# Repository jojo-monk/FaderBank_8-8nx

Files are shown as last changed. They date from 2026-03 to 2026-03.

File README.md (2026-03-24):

# 8+8nx Faderbank

A modular faderbank based on the [16nx](https://github.com/16n-faderbank/16nx) project, designed for Eurorack synthesizers and DAW MIDI control. Sends MIDI data and CV signals.

---
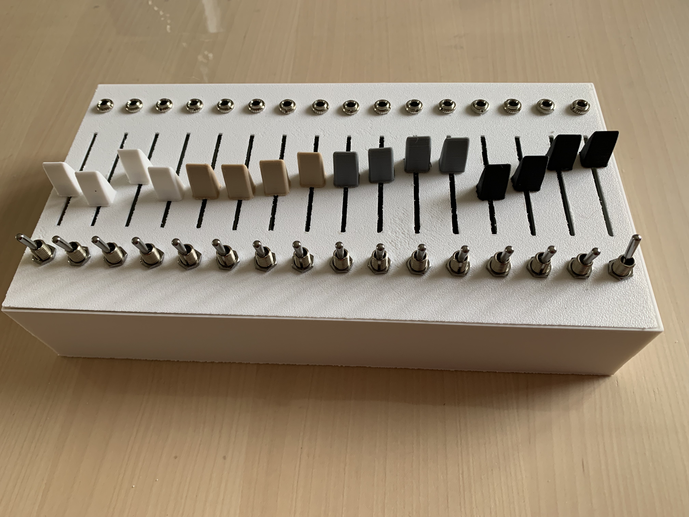
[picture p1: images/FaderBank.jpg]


## What is it?

The 8+8nx is a DIY faderbank that splits the original 16nx design into two separate PCBs, making it more flexible and easier to build in different configurations.

It is designed for musicians who want hands-on control over their Eurorack setup or DAW, with a compact and modular form factor.

---

## Differences from the 16nx

| Feature | 16nx | 8+8nx |
|---|---|---|
| PCB | Single board | 2 PCBs (ControlBoard + MainBoard) |
| Faders | 16 | 8 per ControlBoard (expandable to 16) |
| MCU | RP2040 chip | Raspberry Pi Pico |
| Mute switches | No | Yes, per fader |
| I2C port | Yes | Removed |
| GPIO exposure | Partial | All free Pico pins exposed |

---
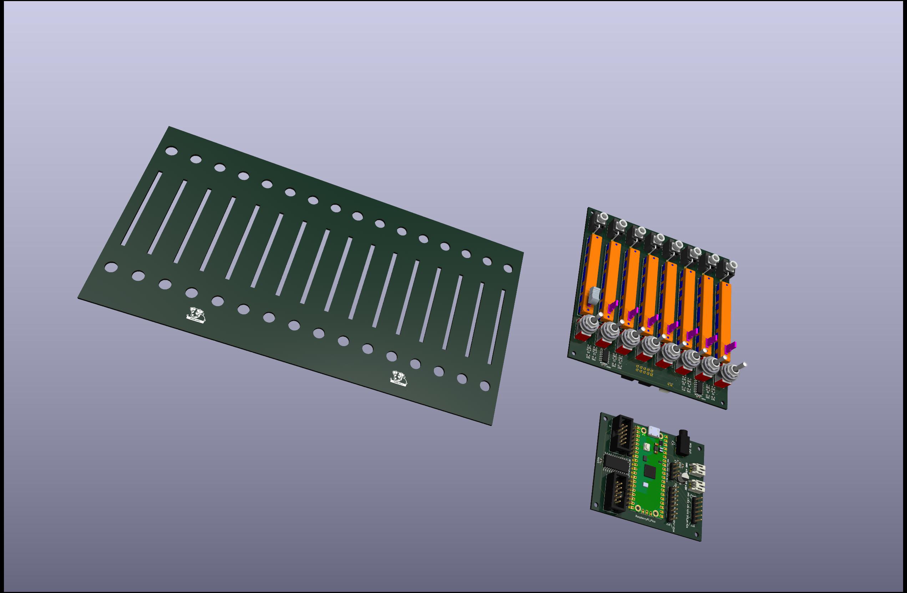
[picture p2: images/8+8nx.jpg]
Rendu 3D


## Hardware

- **MainBoard** — hosts the Raspberry Pi Pico, handles USB MIDI, CV outputs and all connections
- **ControlBoard** — hosts 8 faders and mute switches, connects to the MainBoard

You can run a single ControlBoard (8 faders) or chain two for a full 16-fader setup.

---

## Features

- USB MIDI output
- CV output
- 8 or 16 fader configuration
- Mute switch per fader
- All free GPIO pins of the Raspberry Pi Pico exposed for customization
- Compatible with Eurorack synthesizers and DAWs

---

## Firmware

Based on the 16nx firmware, adapted for the Raspberry Pi Pico.

### Build requirements

- [Raspberry Pi Pico SDK](https://github.com/raspberrypi/pico-sdk)
- CMake 3.13+
- ARM GCC toolchain

### Build

```bash
git clone https://github.com/jojo-monk/8-8nx.git
cd 8-8nx/firmware
mkdir build && cd build
cmake ..
make
```

Flash the resulting `.uf2` file onto your Pico by holding BOOTSEL while plugging it in, then drag and drop the file.

---

## Project status

✅ Tested and working

---

## Credits

Based on the [16nx faderbank](https://github.com/16n-faderbank/16nx) project.

---

## License

Hardware and firmware released under the same license as the original 16nx project.

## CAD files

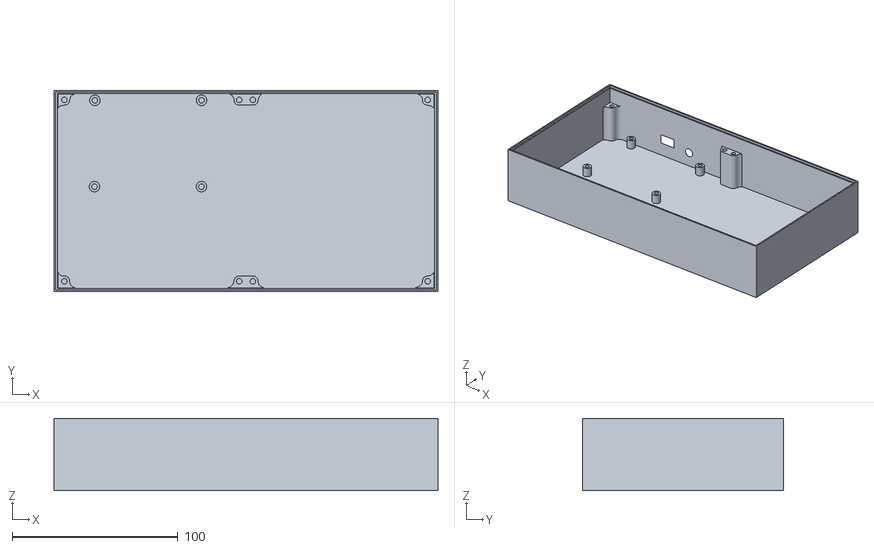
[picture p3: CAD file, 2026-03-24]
3D/88nx-Box.stl
231.9 x 121.6 x 43.5

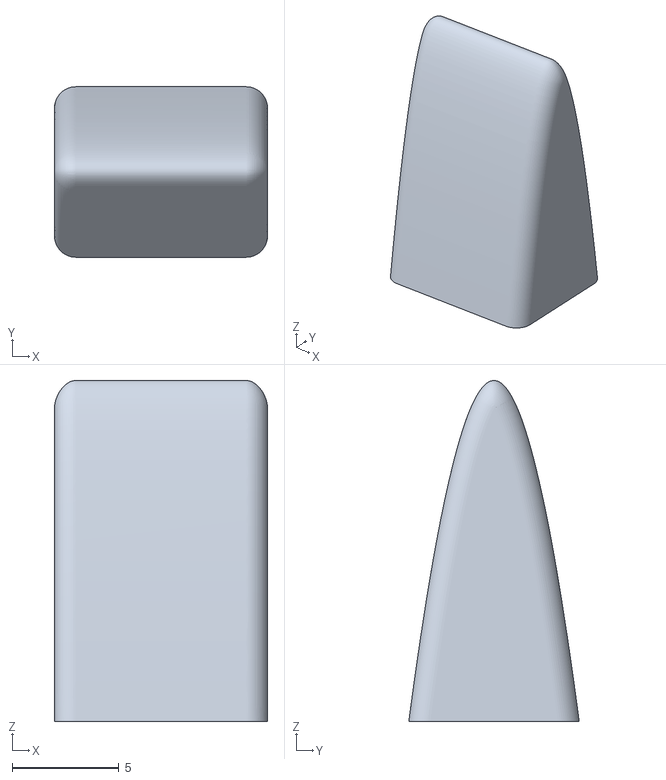
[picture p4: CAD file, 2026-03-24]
3D/fader.stl
10.0 x 8.00 x 16.0

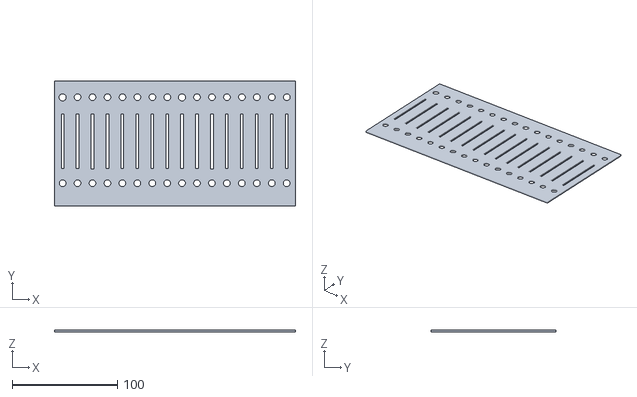
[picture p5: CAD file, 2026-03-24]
3D/8nx-panel.stl
229.0 x 119.0 x 1.51

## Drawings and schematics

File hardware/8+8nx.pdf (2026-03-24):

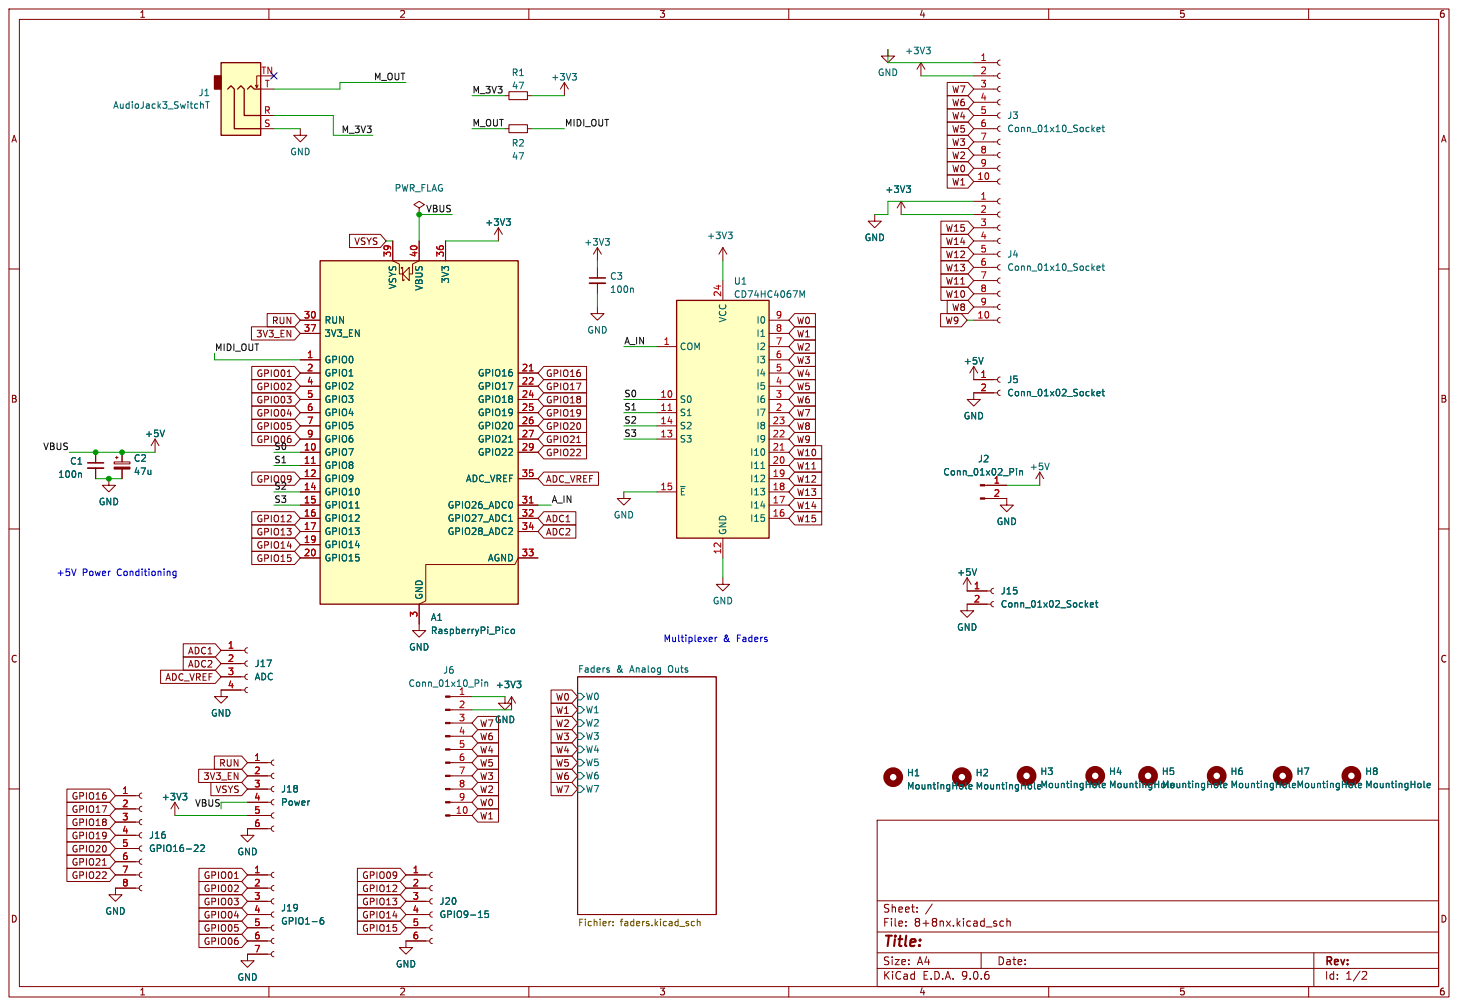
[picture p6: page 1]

Id: 1/2 Title: File: 8+8nx.kicad_sch Sheet: / W0 W7 W6 W3 W2 W4 W5 W1 Faders & Analog Outs Fichier: faders.kicad_sch

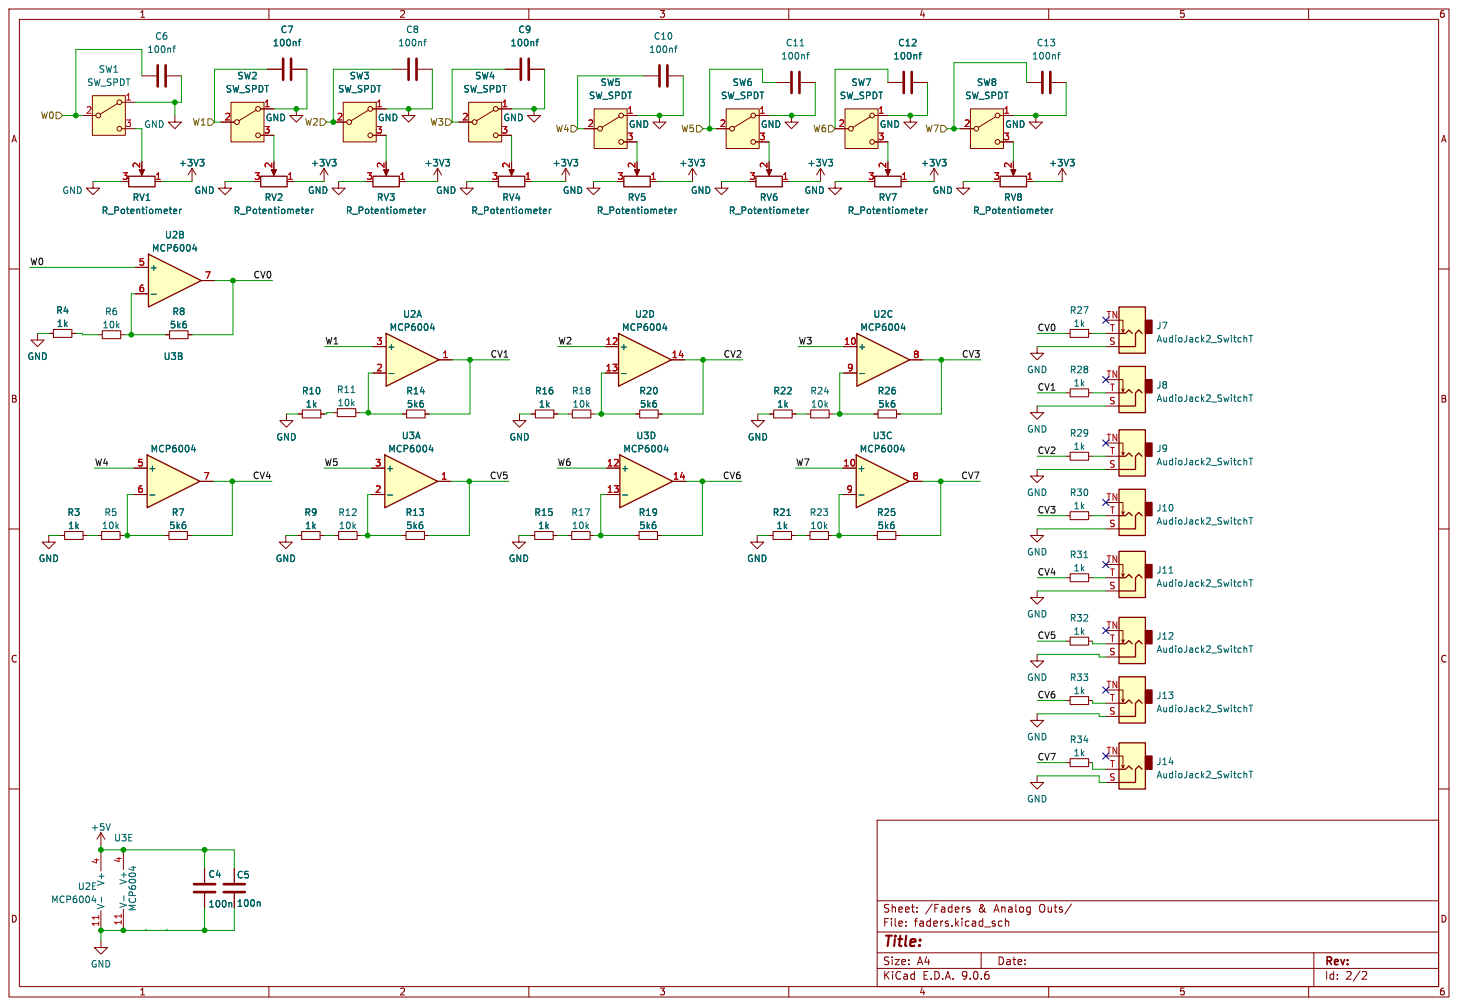
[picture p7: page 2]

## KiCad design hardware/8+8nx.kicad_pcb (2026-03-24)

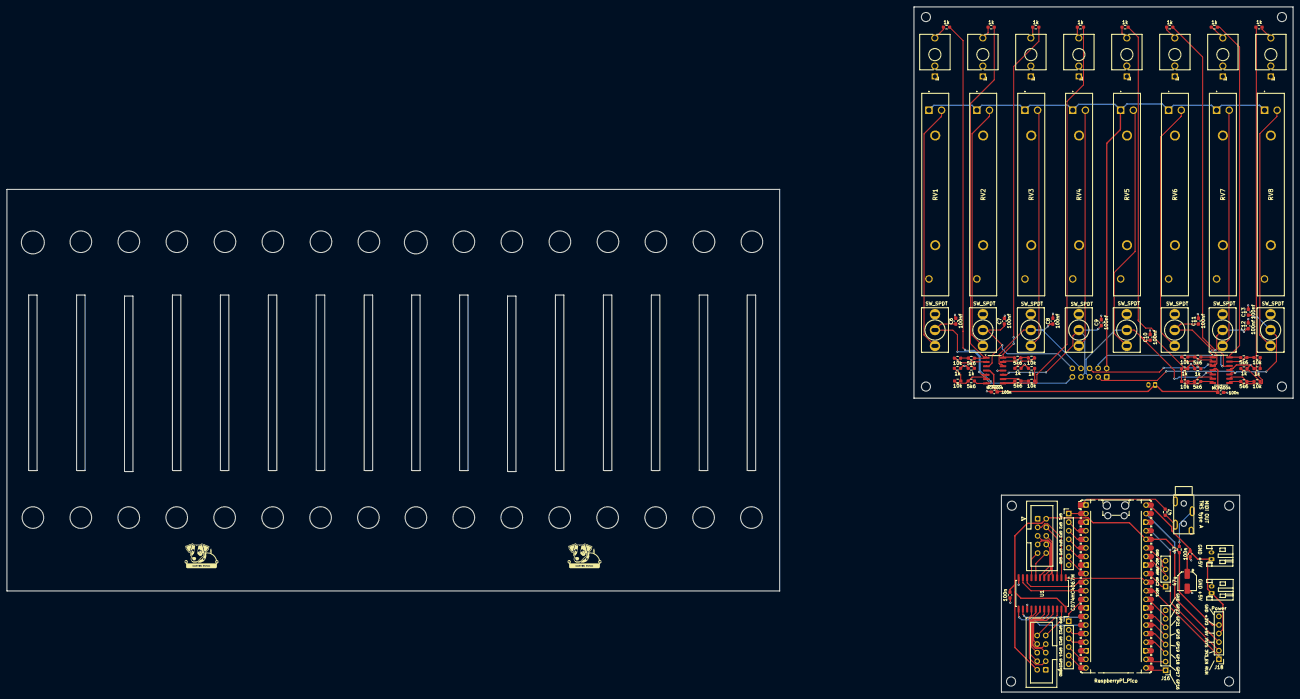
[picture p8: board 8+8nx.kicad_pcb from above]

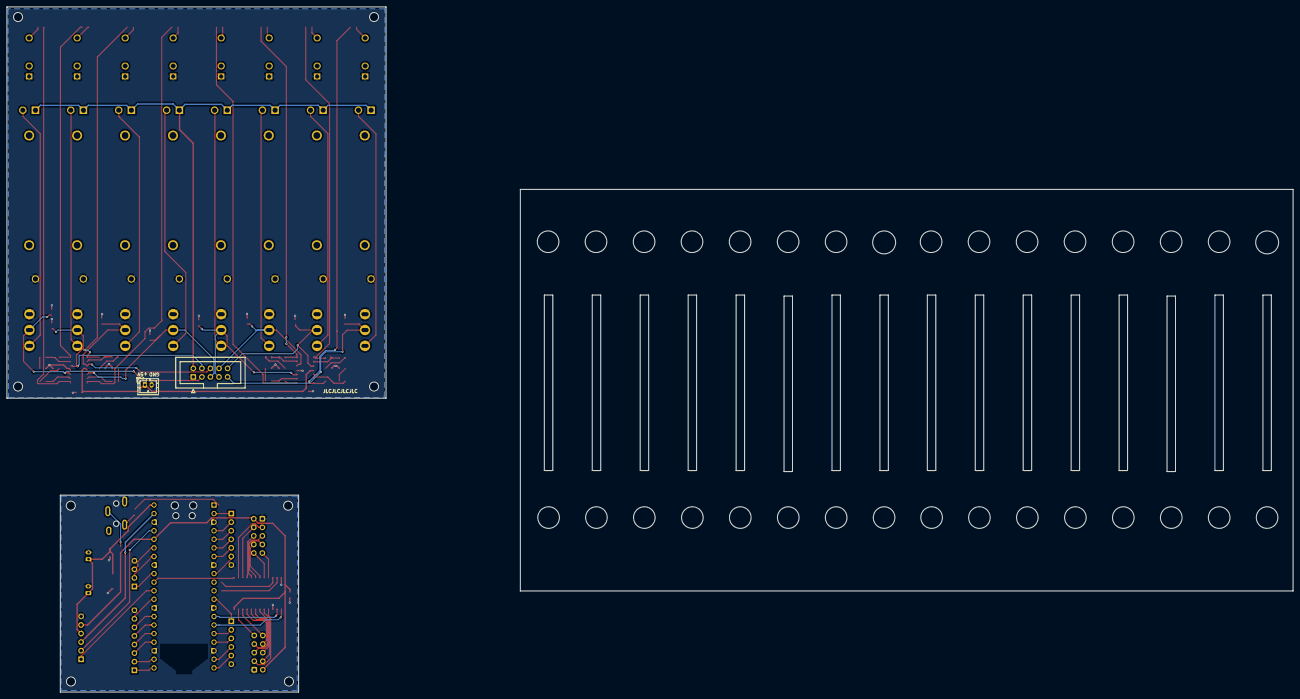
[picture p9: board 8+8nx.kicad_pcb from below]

Board: 2 copper layers, 112.4 x 116.0 mm, 95 parts (2 on the bottom side), 91 nets.

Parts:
A1: RaspberryPi_Pico; RaspberryPi_Pico_Common_Unspecified
C1, C3, C4, C5: 100n; C_0603_1608Metric_Pad1.08x0.95mm_HandSolder
C2: 47u; CP_Elec_5x5.4
C6, C7, C8, C9, C10, C11, C12, C13: 100nf; C_0603_1608Metric_Pad1.08x0.95mm_HandSolder
H1, H2, H3, H4, H5, H6, H7, H8: MountingHole; MountingHole_2.7mm_M2.5
J1: AudioJack3_SwitchT; Schurter 4832.2330
J2: Conn_01x02_Pin; JST_PH_S2B-PH-K_1x02_P2.00mm_Horizontal
J3, J4: Conn_01x10_Socket; IDC-Header_2x05_P2.54mm_Vertical
J5: Conn_01x02_Socket; JST_PH_B2B-PH-K_1x02_P2.00mm_Vertical
J6: Conn_01x10_Pin; IDC-Header_2x05_P2.54mm_Vertical
J7, J8, J9, J10, J11, J12, J13, J14: AudioJack2_SwitchT; AudioJack_3.5mm
J15: Conn_01x02_Socket; JST_PH_S2B-PH-K_1x02_P2.00mm_Horizontal
J16: GPIO16-22; PinHeader_1x08_P2.54mm_Vertical
J17: ADC; PinHeader_1x04_P2.54mm_Vertical
J18: Power; PinHeader_1x06_P2.54mm_Vertical
J19: GPIO1-6; PinHeader_1x07_P2.54mm_Vertical
J20: GPIO9-15; PinHeader_1x06_P2.54mm_Vertical
R1, R2: 47; R_0603_1608Metric_Pad0.98x0.95mm_HandSolder
R3, R4, R9, R10, R15, R16, R21, R22, R27, R28, R29, R30, R31, R32, R33, R34: 1k; R_0603_1608Metric_Pad0.98x0.95mm_HandSolder
R5, R6, R11, R12, R17, R18, R23, R24: 10k; R_0603_1608Metric_Pad0.98x0.95mm_HandSolder
R7, R8, R13, R14, R19, R20, R25, R26: 5k6; R_0603_1608Metric_Pad0.98x0.95mm_HandSolder
RV1, RV2, RV3, RV4, RV5, RV6, RV7, RV8: R_Potentiometer; RS45111A900F
SW1, SW2, SW3, SW4, SW5, SW6, SW7, SW8: SW_SPDT; Switch_Toggle_SPDT_Mini_SolderLug
U1: CD74HC4067M; SOIC-24W_7.5x15.4mm_P1.27mm
U2, U3: MCP6004; SOIC-14_3.9x8.7mm_P1.27mm

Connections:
3V3_EN: A1.37 (3V3_EN), J18.2
+3V3: A1.36 (3V3), C3.1, J3.2, J4.2, J6.2, J18.5, R1.2, RV1.1, RV2.1, RV3.1, RV4.1, RV5.1, RV6.1, RV7.1, RV8.1, U1.24 (VCC)
+5V: A1.40 (VBUS), C1.1, C2.1, C4.1, C5.1, J2.1, J5.1, J15.1, J18.4, U2.4 (V+), U3.4 (V+)
/A_IN: A1.31 (GPIO26_ADC0), U1.1 (COM)
/Faders & Analog Outs/CV0: R8.1, R27.1, U2.7
/Faders & Analog Outs/CV1: R14.1, R28.1, U2.1
/Faders & Analog Outs/CV2: R20.1, R29.1, U2.14
/Faders & Analog Outs/CV3: R26.1, R30.1, U2.8
/Faders & Analog Outs/CV4: R7.1, R31.1, U3.7
/Faders & Analog Outs/CV5: R13.1, R32.1, U3.1
/Faders & Analog Outs/CV6: R19.1, R33.1, U3.14
/Faders & Analog Outs/CV7: R25.1, R34.1, U3.8
/MIDI_OUT: A1.1 (GPIO0), R2.2
/M_3V3: J1.R, R1.1
/M_OUT: J1.T, R2.1
/S0: A1.10 (GPIO7), U1.10 (S0)
/S1: A1.11 (GPIO8), U1.11 (S1)
/S2: A1.14 (GPIO10), U1.14 (S2)
/S3: A1.15 (GPIO11), U1.13 (S3)
ADC1: A1.32 (GPIO27_ADC1), J17.1
ADC2: A1.34 (GPIO28_ADC2), J17.2
ADC_VREF: A1.35 (ADC_VREF), J17.3
GND: A1.3 (GND), A1.8 (GND), A1.13 (GND), A1.18 (GND), A1.23 (GND), A1.28 (GND), A1.38 (GND), C1.2, C2.2, C3.2, C4.2, C5.2, C6.2, C7.2, C8.2, C9.2, C10.2, C11.2, C12.2, C13.2, J1.S, J2.2, J3.1, J4.1, J5.2, J6.1, J7.S, J8.S, J9.S, J10.S, J11.S, J12.S, J13.S, J14.S, J15.2, J16.8, J17.4, J18.6, J19.7, J20.6, R3.2, R4.2, R9.2, R10.2, R15.2, R16.2, R21.2, R22.2, RV1.3, RV2.3, RV3.3, RV4.3, RV5.3, RV6.3, RV7.3, RV8.3, SW1.1 (A), SW2.1 (A), SW3.1 (A), SW4.1 (A), SW5.1 (A), SW6.1 (A), SW7.1 (A), SW8.1 (A), U1.12 (GND), U1.15 (~E), U2.11 (V-), U3.11 (V-)
GPIO01: A1.2 (GPIO1), J19.1
GPIO02: A1.4 (GPIO2), J19.2
GPIO03: A1.5 (GPIO3), J19.3
GPIO04: A1.6 (GPIO4), J19.4
GPIO05: A1.7 (GPIO5), J19.5
GPIO06: A1.9 (GPIO6), J19.6
GPIO09: A1.12 (GPIO9), J20.1
GPIO12: A1.16 (GPIO12), J20.2
GPIO13: A1.17 (GPIO13), J20.3
GPIO14: A1.19 (GPIO14), J20.4
GPIO15: A1.20 (GPIO15), J20.5
GPIO16: A1.21 (GPIO16), J16.1
GPIO17: A1.22 (GPIO17), J16.2
GPIO18: A1.24 (GPIO18), J16.3
GPIO19: A1.25 (GPIO19), J16.4
GPIO20: A1.26 (GPIO20), J16.5
GPIO21: A1.27 (GPIO21), J16.6
GPIO22: A1.29 (GPIO22), J16.7
unnamed: J7.T, R27.2
unnamed: J8.T, R28.2
unnamed: J9.T, R29.2
unnamed: J10.T, R30.2
unnamed: J11.T, R31.2
unnamed: J12.T, R32.2
unnamed: J13.T, R33.2
unnamed: J14.T, R34.2
unnamed: R3.1, R5.2
unnamed: R4.1, R6.2
unnamed: R10.1, R11.2
unnamed: R9.1, R12.2
unnamed: R15.1, R17.2
unnamed: R16.1, R18.2
unnamed: R21.1, R23.2
unnamed: R22.1, R24.2
unnamed: RV1.2, SW1.3 (C)
unnamed: RV2.2, SW2.3 (C)
unnamed: RV3.2, SW3.3 (C)
unnamed: RV4.2, SW4.3 (C)
unnamed: RV5.2, SW5.3 (C)
unnamed: RV6.2, SW6.3 (C)
unnamed: RV7.2, SW7.3 (C)
unnamed: RV8.2, SW8.3 (C)
unnamed: R11.1, R14.2, U2.2 (-)
unnamed: R6.1, R8.2, U2.6 (-)
unnamed: R24.1, R26.2, U2.9 (-)
unnamed: R18.1, R20.2, U2.13 (-)
unnamed: R12.1, R13.2, U3.2 (-)
unnamed: R5.1, R7.2, U3.6 (-)
unnamed: R23.1, R25.2, U3.9 (-)
unnamed: R17.1, R19.2, U3.13 (-)
RUN: A1.30 (RUN), J18.1
VSYS: A1.39 (VSYS), J18.3
W0: C6.1, J3.9, J6.9, SW1.2 (B), U1.9 (I0), U2.5 (+)
W1: C7.1, J3.10, J6.10, SW2.2 (B), U1.8 (I1), U2.3 (+)
W2: C8.1, J3.8, J6.8, SW3.2 (B), U1.7 (I2), U2.12 (+)
W3: C9.1, J3.7, J6.7, SW4.2 (B), U1.6 (I3), U2.10 (+)
W4: C10.1, J3.5, J6.5, SW5.2 (B), U1.5 (I4), U3.5 (+)
W5: C11.1, J3.6, J6.6, SW6.2 (B), U1.4 (I5), U3.3 (+)
W6: C12.1, J3.4, J6.4, SW7.2 (B), U1.3 (I6), U3.12 (+)
W7: C13.1, J3.3, J6.3, SW8.2 (B), U1.2 (I7), U3.10 (+)
W8: J4.9, U1.23 (I8)
W9: J4.10, U1.22 (I9)
W10: J4.8, U1.21 (I10)
W11: J4.7, U1.20 (I11)
W12: J4.5, U1.19 (I12)
W13: J4.6, U1.18 (I13)
W14: J4.4, U1.17 (I14)
W15: J4.3, U1.16 (I15)

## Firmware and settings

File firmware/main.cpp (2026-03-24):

/**
 * 16Next firmware
 *
 * See README.md for pinout / circuit configuration
 * Tom Armitage [tom@infovore.org]
 */

#include <stdio.h>
#include "hardware/adc.h"
#include "hardware/gpio.h"
#include "hardware/i2c.h"
#include "pico/binary_info.h"
//#include "pico/i2c_slave.h"
#include "pico/stdlib.h"

#include "bsp/board.h"
#include "midi_uart_lib.h"
#include "tusb.h"

#include "lib/ResponsiveAnalogRead.hpp"
#include "lib/config.h"
#include "lib/flash_onboard.h"
//#include "lib/i2c_utils.h"
#include "lib/sysex.h"
#include "main.h"

uint32_t startTime = to_ms_since_boot(get_absolute_time());
bool stabilized = false;
absolute_time_t updateControlsAt;
absolute_time_t midiActivityLightOffAt;
bool midiActivity            = false;

bool shouldSendControlUpdate = false;
absolute_time_t sendForcedUpdateAt;

ControllerConfig controller; // struct to hold controller config

uint8_t sysexBuffer[128]; // 128 bytes to store incoming sysex in
bool isReadingSysex     = false;
uint8_t sysexOffset     = 0; // where in the buffer we start writing to.

// this maps faders to Mux positions, ie,
// fader 6 is on mux input 0,
// fader 4 is on mux input 1
const int faderLookup[] = {0, 1, 2, 3, 4, 5, 6, 7, 8, 9, 10, 11, 12, 13, 14, 15};
const uint mux_pins[MUX_PIN_COUNT] = {MUX_S0, MUX_S1, MUX_S2, MUX_S3};
uint16_t previousValues[16];
int i2cData[16];
int muxMask;

ResponsiveAnalogRead *analog[FADER_COUNT]; // array of filters to smooth analog read.

static void *midi_uart_instance;

// active input for I2C
int activeInput = 0;

void setMuxChannel(uint8_t channel) {
    for (int i = 0; i < 4; i++) {
        gpio_put(mux_pins[i], (channel >> i) & 0x01);
    }
}
int main() {
  board_init();

  stdio_init_all();

  bi_decl(bi_1pin_with_name(INTERNAL_LED_PIN, "On-board LED"));
  bi_decl(bi_2pins_with_names(MIDI_UART_TX_GPIO, "MIDI UART TX", MIDI_UART_RX_GPIO, "MIDI UART RX"));
  // for (uint8_t i = 0; i < MUX_PIN_COUNT; i++) {
  // bi_decl(bi_1pin_with_name(FIRST_MUX_PIN + i, "Mux Pin"));
  // }
  bi_decl(bi_4pins_with_names(FIRST_MUX_PIN, "Mux Address Pin 0", FIRST_MUX_PIN + 1, "Mux Address Pin 1", FIRST_MUX_PIN + 2, "Mux Address Pin 2", FIRST_MUX_PIN + 3, "Mux Address Pin 3"));

  loadConfig(&controller, true); // load config from flash; write default config TO flash if byte 1 is 0xFF

  if (controller.i2cLeader) {
    sleep_ms(BOOTDELAY);
  }

  // init ADC0 on GPIO26
  adc_init();
  adc_gpio_init(ADC_PIN);
  adc_select_input(0);

  // // setup mux pins
  // for (int i = 0; i < MUX_PIN_COUNT; i++) {
  //   muxMask |= 1 << i + FIRST_MUX_PIN;
  // }
  // gpio_init_mask(muxMask);
  // gpio_set_dir_out_masked(muxMask);
  for (int i = 0; i < MUX_PIN_COUNT; i++) {
    gpio_init(mux_pins[i]);
    gpio_set_dir(mux_pins[i], GPIO_OUT);
}

  // setup internal led
  gpio_init(INTERNAL_LED_PIN);
  gpio_set_dir(INTERNAL_LED_PIN, GPIO_OUT);

  // setup TRS MIDI
  midi_uart_instance = midi_uart_configure(MIDI_UART_NUM, MIDI_UART_TX_GPIO, MIDI_UART_RX_GPIO);

  // setup analog read buckets
  for (int i = 0; i < FADER_COUNT; i++) {
    analog[i] = new ResponsiveAnalogRead(0, true, .05);
    analog[i]->setActivityThreshold(16);
    // analog[i]->enableEdgeSnap();
  }

  // set up I2C on jack
  // GPIO 10 = I2C1 SDA
  // GPIO 11 = I2C1 SCL
  //gpio_init(I2C_SDA_PIN);
  //gpio_init(I2C_SCL_PIN);
  // gpio_set_function(I2C_SDA_PIN, GPIO_FUNC_I2C);
  // gpio_set_function(I2C_SCL_PIN, GPIO_FUNC_I2C);
  // gpio_pull_up(I2C_SDA_PIN);
  // gpio_pull_up(I2C_SCL_PIN);
  // Make the I2C pins available to picotool
  //bi_decl(bi_2pins_with_func(I2C_SDA_PIN, I2C_SCL_PIN, GPIO_FUNC_I2C));

  // if (controller.i2cLeader) {
  //   i2c_init(i2c1, I2C_BAUDRATE);
  //   scanI2Cbus();
  // } else {
  //   i2c_init(i2c1, I2C_BAUDRATE);
  //   // configure I2C0 for slave mode
  //   i2c_slave_init(i2c1, I2C_ADDRESS, &i2c_slave_handler);
  // }

  // init TinyUSB
  tusb_init();

  // make sure LED is off.
  gpio_put(INTERNAL_LED_PIN, 0);
  // end setup

  // begin infinite loop
  uint32_t currentTime = to_ms_since_boot(get_absolute_time());

if (!stabilized && (currentTime - startTime > 2000)) {
    stabilized = true; // On attend 2 secondes avant d'autoriser l'envoi MIDI
}

if (stabilized) {
    // Ici, ton code qui envoie les messages MIDI
  while (true) {
    // do the TinyUSB task and midi task - as fast as you can.
    tud_task();
    midi_read_task();

    if (controller.powerLed) {
      gpio_put(INTERNAL_LED_PIN, true);
    } else {
      gpio_put(INTERNAL_LED_PIN, controller.midiLed && midiActivity);
    }

    if (absolute_time_diff_us(midiActivityLightOffAt, get_absolute_time()) > 0) {
      midiActivity = false;
    }

    if (shouldSendControlUpdate && absolute_time_diff_us(sendForcedUpdateAt, get_absolute_time()) > 0) {
      // we've received a sysex "give me your config request" recently
      // so we should send the state of all controls whether they've changed
      // or not
      updateControls(true);
      shouldSendControlUpdate = false;
    }

    // if it's time to update
    int shouldUpdate =
        absolute_time_diff_us(get_absolute_time(), updateControlsAt) < 0;

    if (!shouldUpdate) {
      // skip to the next main loop
      continue;
    }

    updateControlsAt = make_timeout_time_ms(CONTROL_POLL_TIMEOUT);

    updateControls();

    // drain the TX buffer to the TRS midi out - if you don't include this,
    // no data will ever get sent to the MIDI out.
    midi_uart_drain_tx_buffer(midi_uart_instance);
  }
}
  
  // end infinite loop
}

void midi_read_task() {
  uint8_t inputBuffer[MIDI_INPUT_BUFFER];
  uint8_t streamLength;
  while (tud_midi_available()) {
    streamLength = tud_midi_stream_read(inputBuffer, MIDI_INPUT_BUFFER);
    // if it's not clock...
    if (inputBuffer[0] != 0xF8) {
      midiActivity           = true;
      midiActivityLightOffAt = make_timeout_time_us(MIDI_BLINK_DURATION);
    }
  }

  if (isReadingSysex) {
    // keep doing sysex stuff
    bool sysexComplete = copySysexStreamToBuffer(sysexBuffer, inputBuffer, streamLength, sysexOffset);

    if (sysexComplete) {
      // we saw an 0xF7, sysex is over, time to process
      processSysexBuffer();
    } else {
      // we still haven't seen the end of message, glue it on the end
      // and process the next 64-byte chunk
      sysexOffset += streamLength;
    }
    return;
  }

  // BEGIN SYSEX HANDLER
  if (inputBuffer[0] == 0xF0 && inputBuffer[1] == 0x7D && inputBuffer[2] == 0x00 && inputBuffer[3] == 0x00) {
    // it's a sysex message and it's for us!

    // start the process of reading it
    isReadingSysex = true;
    sysexOffset    = 0;

    // blank the buffer;
    for (uint8_t i = 0; i < 128; i++) {
      sysexBuffer[i] = 0x00;
    }

    bool sysexComplete = copySysexStreamToBuffer(sysexBuffer, inputBuffer, streamLength, sysexOffset);

    if (sysexComplete) {
      // we saw an 0xF7, sysex is over, time to process
      processSysexBuffer();
    } else {
      // we still haven't seen the end of message, glue it on the end
      // and process the next 64-byte chunk
      sysexOffset += streamLength;
    }
    return;
  }
  // END SYSEX HANDLER

  // if it's not sysex, forward it thru to midi TRS if relevant.
  if (controller.midiThru) {
    midi_uart_write_tx_buffer(midi_uart_instance, inputBuffer, streamLength);
  }
}

void processSysexBuffer() {
  isReadingSysex = false;

  switch (sysexBuffer[4]) {
  case 0x1F:
    // 0x1F == tell me your 1nFo
    sendCurrentConfig();
    shouldSendControlUpdate = true;
    sendForcedUpdateAt      = make_timeout_time_ms(100);
    break;
  case 0x0E:
    // 0x0E == c0nfig Edit
    updateConfig(sysexBuffer, 128, &controller);
    break;
  case 0x1A:
    // 0x1A == initi1Alize to factory defaults
    setDefaultConfig();
    loadConfig(&controller);
    break;
  }
}

void updateControls(bool force) {
  if (force) {
    // "force" only happens when connecting via sysex initially
    // ie, it's for the 'first load' of the editor. So we can lock up for 1ms.
    busy_wait_us(1000);
  }
  for (int i = 0; i < FADER_COUNT; i++) {
    // convert our number to binary, and turn it into a valid output mask
    // do this by working out a binary representation of channel ID
    // uint controllerId = faderLookup[i] << FIRST_MUX_PIN;
    // gpio_put_masked(muxMask, controllerId);
    setMuxChannel(faderLookup[i]);
    busy_wait_us(10); // wait for mux pins to swap
    
    uint16_t rawAdcValue = adc_read();
#ifdef INVERT_ADC
    rawAdcValue = (1 << ADC_RESOLUTION) - 1 - rawAdcValue;
#endif
    analog[i]->update(rawAdcValue);

    uint8_t controllerIndex = i;

    if (controller.rotated) {
      controllerIndex = FADER_COUNT - 1 - i;
    }

    if (analog[i]->hasChanged() || force) {
      if (force) {
        // if we're being asked to update all our values, we _really_ would like a read, please.
        analog[i]->update(rawAdcValue);
      }

      // store the current value of the fader in this block
      // for i2c purposes
      // i2c resolution is 14-bit on 16n.
      // 16nx has a 12-bit max ADC, but we want compatibility with other
      // scripts. And so bit shift by 2 to scale up to 14-bit data.:
      // i2cData[i] = analog[i]->getValue() << 2;
      // if (controller.rotated) {
      //   i2cData[i] = ((1 << 14) - 1) - i2cData[i];
      // }

      // test the scaled version against the previous CC.
      uint16_t usbOutputValue;
      uint16_t trsOutputValue;
      bool usbHighResolution = controller.rotated ? controller.usbHighResolution[controllerIndex] : controller.usbHighResolution[controllerIndex];
      bool trsHighResolution = controller.rotated ? controller.trsHighResolution[controllerIndex] : controller.trsHighResolution[controllerIndex];

      uint8_t usbOutputBits  = usbHighResolution ? 14 : 7;
      uint8_t trsOutputBits  = trsHighResolution ? 14 : 7;

      usbOutputValue         = usbHighResolution ? analog[i]->getValue() << 2 : analog[i]->getValue() >> 5;
      trsOutputValue         = trsHighResolution ? analog[i]->getValue() << 2 : analog[i]->getValue() >> 5;

      if ((usbOutputValue != previousValues[i]) || force) {
        previousValues[i] = usbOutputValue; // yes, I know USB is driving things.

        if (controller.rotated) {
          usbOutputValue = ((1 << usbOutputBits) - 1) - usbOutputValue;
          trsOutputValue = ((1 << trsOutputBits) - 1) - trsOutputValue;
        }

        // Send CC on appropriate USB channel
        uint8_t cable_num = 0;
        if (usbHighResolution) {
          uint8_t msb          = (usbOutputValue >> 7) & 0x7F;
          uint8_t lsb          = usbOutputValue & 0x7F;

          uint8_t msbCCData[3] = {(uint8_t)(0xB0 | controller.usbMidiChannels[controllerIndex] - 1), controller.usbCCs[controllerIndex], msb};
          uint8_t lsbCCData[3] = {(uint8_t)(0xB0 | controller.usbMidiChannels[controllerIndex] - 1), uint8_t(controller.usbCCs[controllerIndex] + 32), lsb};

          tud_midi_stream_write(cable_num, msbCCData, 3);
          tud_midi_stream_write(cable_num, lsbCCData, 3);
        } else {
          uint8_t ccData[3] = {(uint8_t)(0xB0 | controller.usbMidiChannels[controllerIndex] - 1), controller.usbCCs[controllerIndex],
                               usbOutputValue};
          tud_midi_stream_write(cable_num, ccData, 3);
        }

        // Send CC on appropiate TRS channel
        // TODO: if TRS high resolution
        if (trsHighResolution) {
          uint8_t msb              = (trsOutputValue >> 7) & 0x7F;
          uint8_t lsb              = trsOutputValue & 0x7F;

          uint8_t trs_msbCCData[3] = {(uint8_t)(0xB0 | controller.trsMidiChannels[controllerIndex] - 1), controller.trsCCs[controllerIndex], msb};
          uint8_t trs_lsbCCData[3] = {(uint8_t)(0xB0 | controller.trsMidiChannels[controllerIndex] - 1), uint8_t(controller.trsCCs[controllerIndex] + 32), lsb};
          // tud_midi_stream_write(cable_num, cc, 3);
          midi_uart_write_tx_buffer(midi_uart_instance, trs_msbCCData, 3);
          midi_uart_write_tx_buffer(midi_uart_instance, trs_lsbCCData, 3);
        } else {
          uint8_t ccData[3] = {(uint8_t)(0xB0 | controller.usbMidiChannels[controllerIndex] - 1), uint8_t(controller.usbCCs[controllerIndex]),
                               uint8_t(trsOutputValue)};
          midi_uart_write_tx_buffer(midi_uart_instance, ccData, 3);
        }

        midiActivity           = true;
        midiActivityLightOffAt = make_timeout_time_us(MIDI_BLINK_DURATION);
      }

      // if (controller.i2cLeader) {
      //   sendToAllI2C(i, i2cData[i]);
      // }
    }
  }
}

// Our handler is called from the I2C ISR, so it must complete quickly. Blocking calls /
// printing to stdio may interfere with interrupt handling.
// static void i2c_slave_handler(i2c_inst_t *i2c, i2c_slave_event_t event) {
//   uint16_t shiftReady = 0;
//   uint16_t outputValue;
//   uint8_t incoming;

//   switch (event) {
//   case I2C_SLAVE_RECEIVE: // master has written some data
//     // parse the response
//     activeInput = i2c_read_byte_raw(i2c);
//     if (activeInput < 0) {
//       activeInput = 0;
//     }
//     if (activeInput > FADER_COUNT - 1) {
//       activeInput = FADER_COUNT - 1;
//     }

//     break;
//   case I2C_SLAVE_REQUEST: // master is requesting data
//     // received an i2c read request

//     // get the appropriate value
//     shiftReady = i2cData[activeInput];

//     // send the puppy as MSB/LSB
//     i2c_write_byte_raw(i2c, shiftReady >> 8);
//     i2c_write_byte_raw(i2c, shiftReady & 255);
//     break;
//   case I2C_SLAVE_FINISH: // master has signalled Stop / Restart
//     break;
//   default:
//     break;
//   }
// }

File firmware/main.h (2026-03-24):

/*
 * 16next Header file
 *
 */

//#include "pico/i2c_slave.h"

#define FIRMWARE_VERSION_MAJOR 3
#define FIRMWARE_VERSION_MINOR 1
#define FIRMWARE_VERSION_POINT 1

#define FADER_COUNT            16

#define MEMORY_MAP_LENGTH      86

// define the board type here:
// SIXTEEN_RX = 16rx
// SIXTEEN_NX = 16nx
// SIXTEEN_NEXT_DEV_BOARD = 16next dev board
#define SIXTEEN_NX_V2             1

#ifdef SIXTEEN_NEXT_DEV_BOARD
#define FIRST_MUX_PIN    18
#define MUX_PIN_COUNT    4
#define ADC_PIN          26
#define INTERNAL_LED_PIN 22
#define I2C_SDA_PIN      10
#define I2C_SCL_PIN      11
#define DEVICE_INDEX     5
#elif SIXTEEN_RX
#define FIRST_MUX_PIN    18
#define MUX_PIN_COUNT    4
#define ADC_PIN          26
#define INTERNAL_LED_PIN 2
#define I2C_SDA_PIN      10
#define I2C_SCL_PIN      11
#define DEVICE_INDEX     4
#elif SIXTEEN_NX
#define FIRST_MUX_PIN    18
#define MUX_PIN_COUNT    4
#define ADC_PIN          26
#define INTERNAL_LED_PIN 2
//#define I2C_SDA_PIN      10
//#define I2C_SCL_PIN      11
#define DEVICE_INDEX     5
// #define INVERT_ADC 1// pots appear to be wired in reverse?
#elif SIXTEEN_NX_V2
#define MUX_S0 7   
#define MUX_S1 8   
#define MUX_S2 10  
#define MUX_S3 11  
#define FIRST_MUX_PIN    7
#define MUX_PIN_COUNT    4
#define ADC_PIN          26
#define INTERNAL_LED_PIN 25
#define DEVICE_INDEX     5
#endif

#define ADC_RESOLUTION      12

// I2C Address for Faderbank. 0x34 unless you ABSOLUTELY know what you are doing.
#define I2C_ADDRESS         0x34
#define I2C_BAUDRATE        400000

// define startup delay in milliseconds for i2c Leader devices
// this gives follower devices time to boot up.
#define BOOTDELAY           10000

#define MIDI_BLINK_DURATION 5000 // us

// UART selection Pin mapping. You can move these for your design if you want to
// Make sure all these values are consistent with your choice of midi_uart
// The default is to use UART 1, but you are free to use UART 0 if you make
// the changes in the CMakeLists.txt file or in your environment. Note
// that if you use UART0, then serial port debug will not be enabled
#ifndef MIDI_UART_NUM
#define MIDI_UART_NUM 1
#endif
#ifndef MIDI_UART_TX_GPIO
#define MIDI_UART_TX_GPIO 4
#endif
#ifndef MIDI_UART_RX_GPIO
#define MIDI_UART_RX_GPIO 5
#endif

#define MIDI_INPUT_BUFFER    64

#define CONTROL_POLL_TIMEOUT 10 // ms

/*
 * Functions appearing in 16next.cpp
 */

void midi_read_task();
void updateControls(bool force = false);
//static void i2c_slave_handler(i2c_inst_t *i2c, i2c_slave_event_t event);
void processSysexBuffer();
